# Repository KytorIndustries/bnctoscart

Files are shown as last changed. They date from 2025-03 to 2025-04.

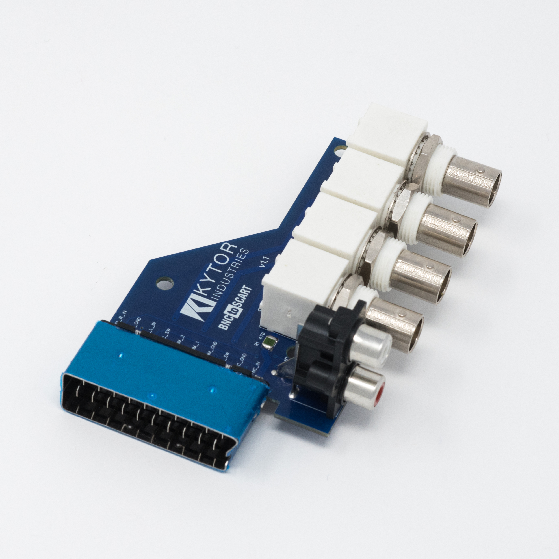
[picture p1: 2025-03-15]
photos/DSC_7843.jpg

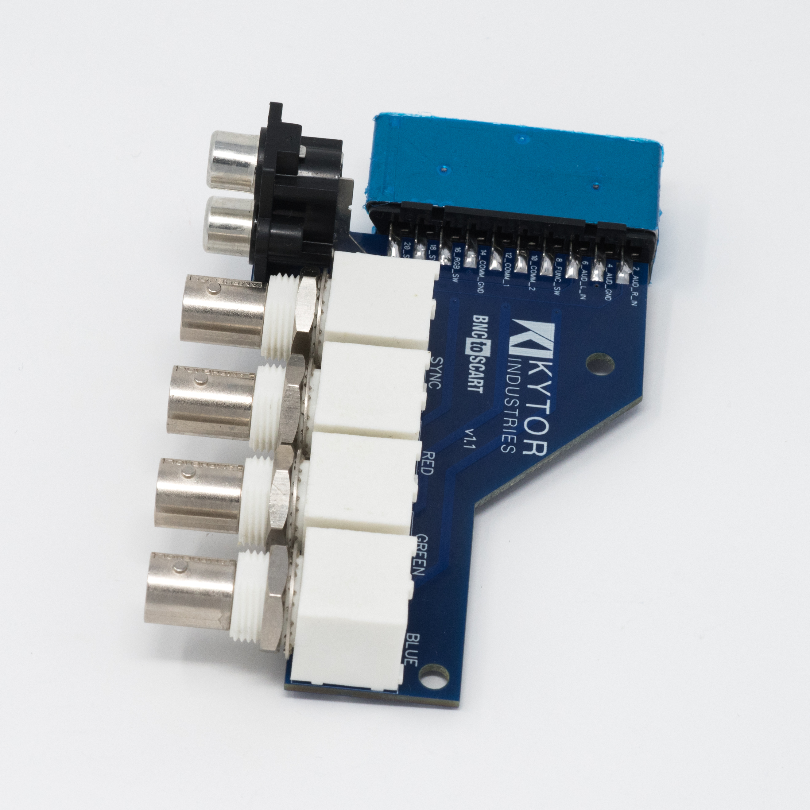
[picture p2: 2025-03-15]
photos/DSC_7844.jpg

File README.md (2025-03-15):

# BNCtoSCART
Connect an RGBs (Red, Green, Blue, CSync) signal over BNC and Stereo Audio signal over RCA to your RetroTINK-5X Pro through the side SCART connection. 

Typical use case would be with a Extron Crosspoint or daisy-chain from the output of a PVM, TTL CSYNC only (jumper included for 75 ohm CSYNC). Connections are turned 90° so they are facing backwards, creating a simple and clean cable management path in your entertainment system.

Fully assembled and QC tested BNCtoSCART adapters can be [purchased here](https://kytor.com/store/product/bnctoscart/).

- Input: 4x [BNC] and 2x [RCA]
- Outputs: 1x [SCART]

BNCtoSCART

## Files Included
- **PCB Design Files** (DipTrace, Gerber)
- **3D Print Files** (STEP, STL, 3MF for Bambu Studio)
- **Bill of Materials** (XLSX)
- **Photos**

## Additional Parts Required
- [2x M3x6 Screws](https://amzn.to/43MXFzS)
- [2x M3x10 Screws](https://amzn.to/43MXFzS)
- [RetroTINK-5X Pro](https://www.retrotink.com/product-page/5x-pro)

## Assembly
1. Solder BNC, RCA and resistor components in place.
2. The flat end SCART connector should be aligned with the board edge, ensure it is properly square and aligned and solder in place.
3. The jumper must only be closed for 75 ohm CSYNC only, otherwise damage to the RetroTINK-5X Pro may result. Do not close this jumper unless you are absolutely certain of 75 ohm CSYNC.
4. Clean the board with isopropyl alchohol, then ultrasonic cleaning is recommended.
5. Apply hot glue to fill the void between the bottom of the RCA connector and the top of the PCB.
6. Secure the PCB assembly to the shell with (2) of M3x6 screws.
7. Screw the shell halves together with (2) of M3x10 screws.

## PCB Revision History
- Ver 1.1 - First production version
- Ver 1.2 - Added sync jumper and screw indication
- Ver 1.3 - Fixed SCART bottom pads alignment (Initial Open Source Release)

## Shell Revision History
- Rev 1 - First production version
- Rev 2 - Modified bottom shell for low profile BNC jacks
- Rev 3 - New internal geometry to print with minimal supports (Initial Open Source Release)

## License
This project is open-source under the [CC BY 4.0 (Attribution 4.0 International)](https://creativecommons.org/licenses/by/4.0/).

## Disclaimer
This project is provided "as-is" without any warranty, express or implied, including but not limited to warranties of merchantability or fitness for a particular purpose. No support is provided.

Amazon links are affiliates.

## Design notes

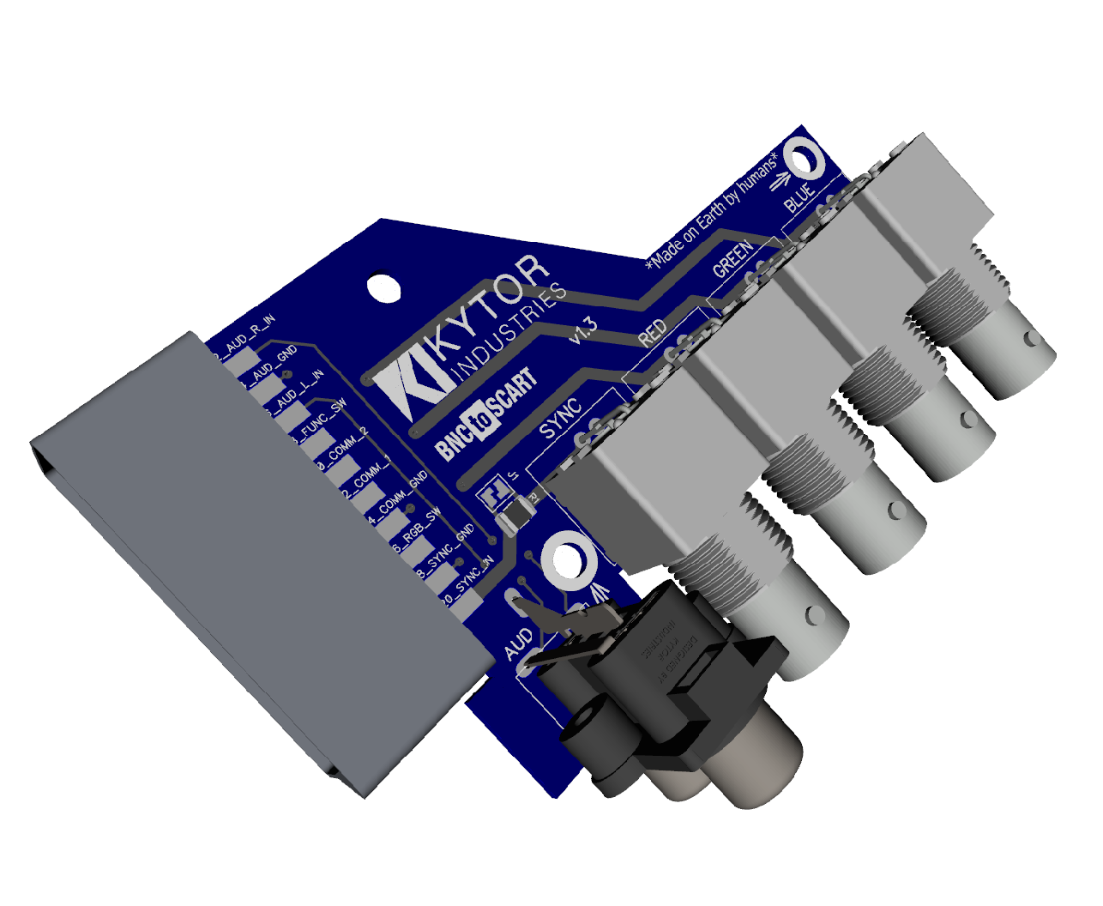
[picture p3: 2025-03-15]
photos/BNCtoSCART-top.png

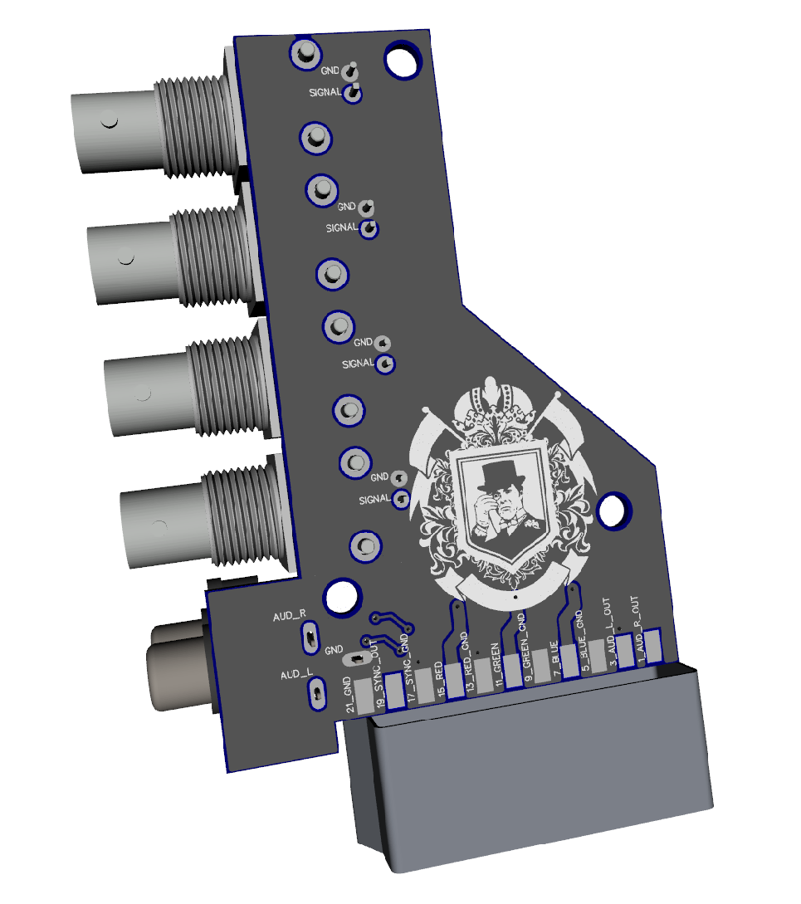
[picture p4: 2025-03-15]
photos/BNCtoSCART-bottom.png

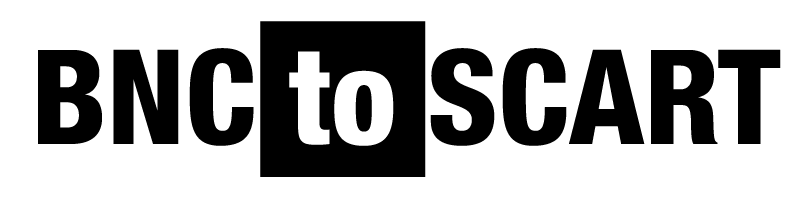
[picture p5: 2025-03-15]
photos/BNCtoSCART.png

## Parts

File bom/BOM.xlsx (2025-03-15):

Name | Manufacturer | Quantity | Value | Pattern | RefDes | Procurement
Female BNC (Right Angle) | Various | 4 |  | Male BNC (Right Angle) | SYNC, RED, GREEN, BLUE | https://www.aliexpress.us/item/2251832788609159.html
Female 2-RCA | Various | 1 |  | 2P | AUD | https://www.aliexpress.us/item/3256803639205455.html
1210 1% SMD Resistor | Various | 1 | 470R | 1210 | R1 | https://www.aliexpress.us/item/2251832770099160.html
Male SCART | Various | 1 |  | MALE SCART | SCART | https://www.aliexpress.us/item/3256803860598518.html

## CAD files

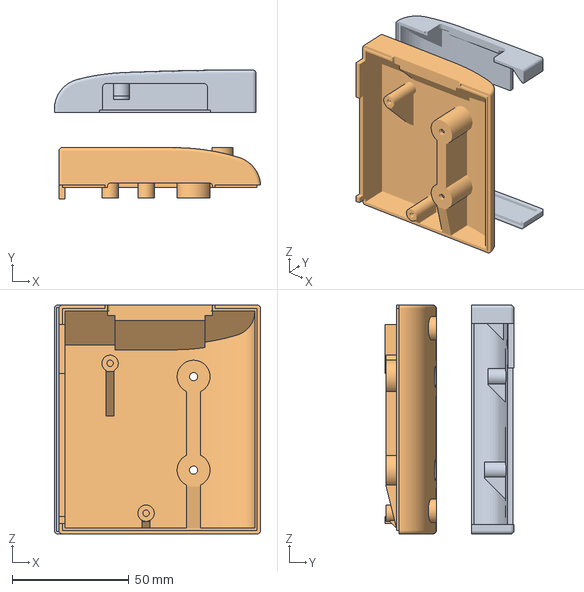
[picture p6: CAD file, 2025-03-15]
shell/BNCtoSCART Shell Full Bambu.3mf
88.3 x 55.3 x 98.0 mm
BNCtoSCART Shell Top - Rev3.STL
BNCtoSCART Shell Bottom - Rev3.STL

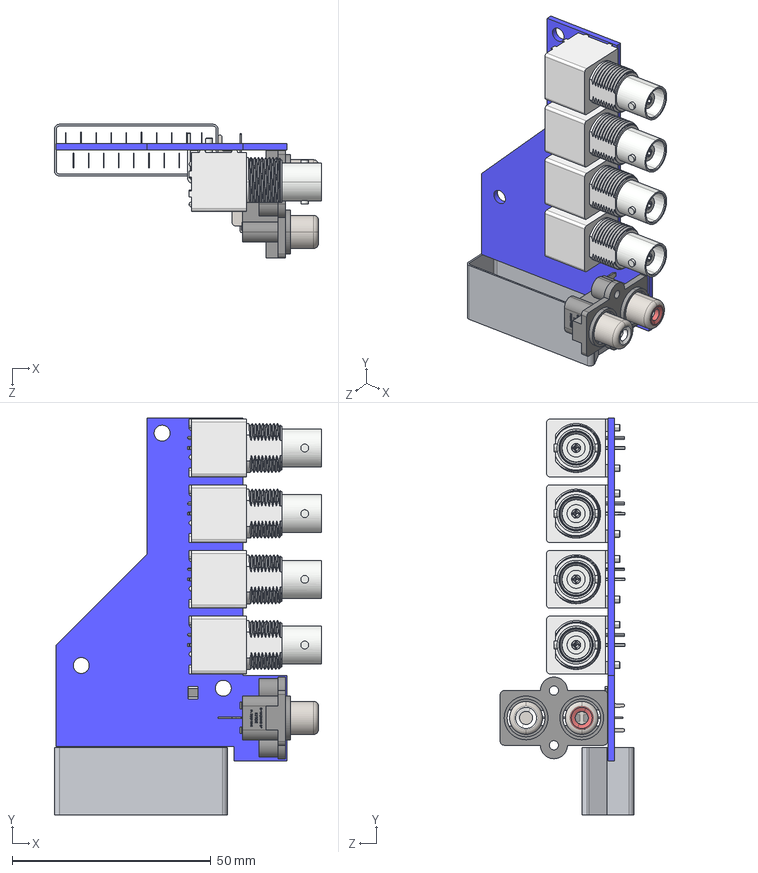
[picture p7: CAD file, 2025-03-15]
pcb/BNC2SCART v1.3.step
67.2 x 99.8 x 33.6 mm
Board_BNC2SCART_v1.3
PCB_Mount_2-RCA_(Designed_by_Kytor_Industries)
BNC_Connector_Male x 4
Male_SCART_End

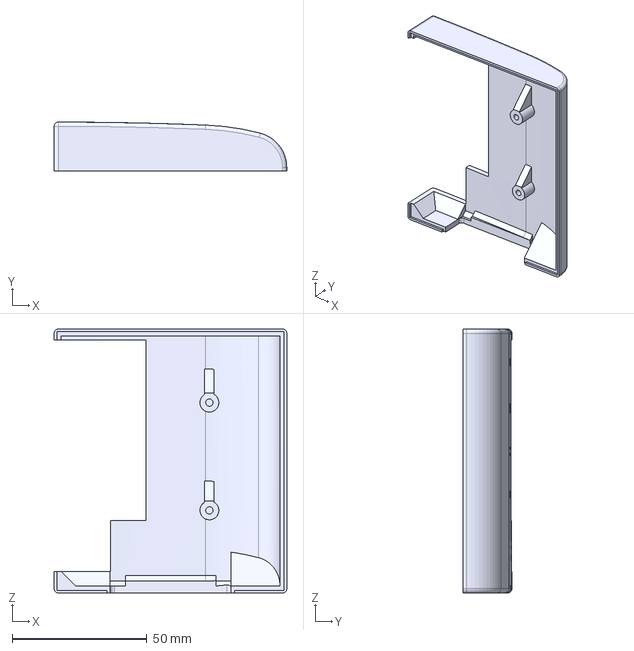
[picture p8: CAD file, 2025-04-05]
shell/BNCtoSCART Shell Top - Rev3.STEP
86.4 x 18.2 x 98.0 mm

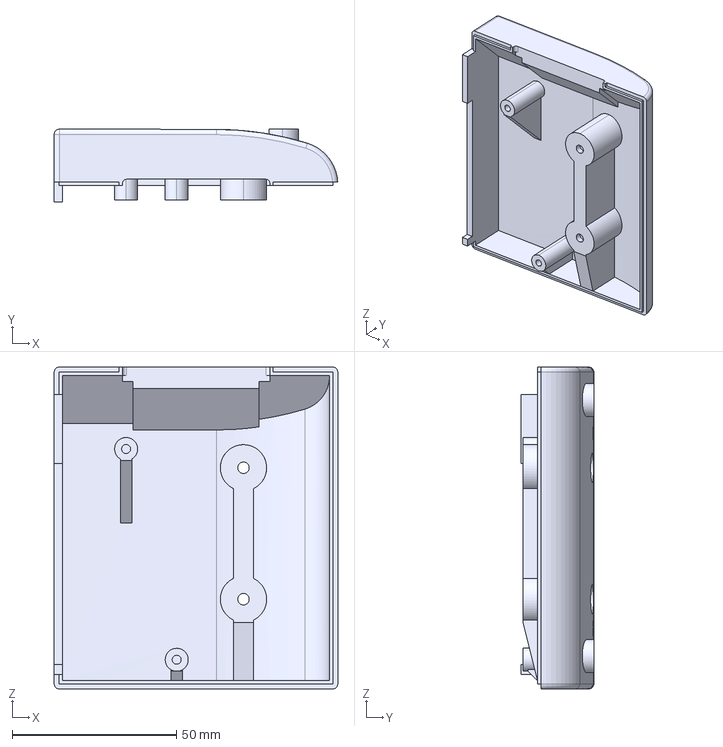
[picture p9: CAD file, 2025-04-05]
shell/BNCtoSCART Shell Bottom - Rev3.STEP
86.3 x 22.1 x 98.0 mm

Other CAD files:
shell/BNCtoSCART Shell Bottom - Rev3.STL
shell/BNCtoSCART Shell Top - Rev3.STL

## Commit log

2025-03-15 Initial Release
    [BNCtoSCART Shell Bottom - Rev3.STEP, BNCtoSCART Shell Bottom - Rev3.STL, BNCtoSCART Shell Full Bambu.3mf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]
2025-03-15 Create BNC2SCART v1.3.step
    [BNC2SCART v1.3.step]
2025-04-05 Updates to STP
    [BNCtoSCART Shell Bottom - Rev3.STEP, BNCtoSCART Shell Top - Rev3.STEP]
